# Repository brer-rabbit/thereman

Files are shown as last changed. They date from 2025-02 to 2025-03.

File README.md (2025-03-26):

# Annoying Thereman - light sensitive buzzing companion

This repo contains the design and build info for Thereman, a light sensitive buzzing companion.  Very useful for a variety of buzzing sounds.

The Thereman contains two LDRs (Light Dependent Resistors) and a dual 555 timer pretty much like an Atari Punk Console.  The LDRs control pitch and pulse width.

# Build

The kit contains a PCB with the dual 555 timer (a 556), the LDRs, eye LEDs, and some passive components on the front, pre-soldered (lead free).  The back requires soldering a couple components.  I'm assuming you're using regular solder wire (if you're using liquid solder I assume you know what you're doing).

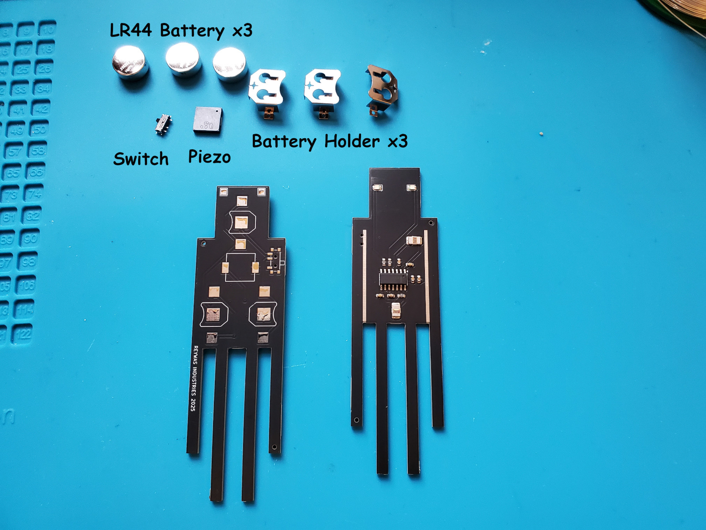
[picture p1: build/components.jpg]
Components shown with front and back of Thereman


## Prep

Tin the pads first.  Shown below, tin the pads marked in green.  The pads in red should not be tinned.

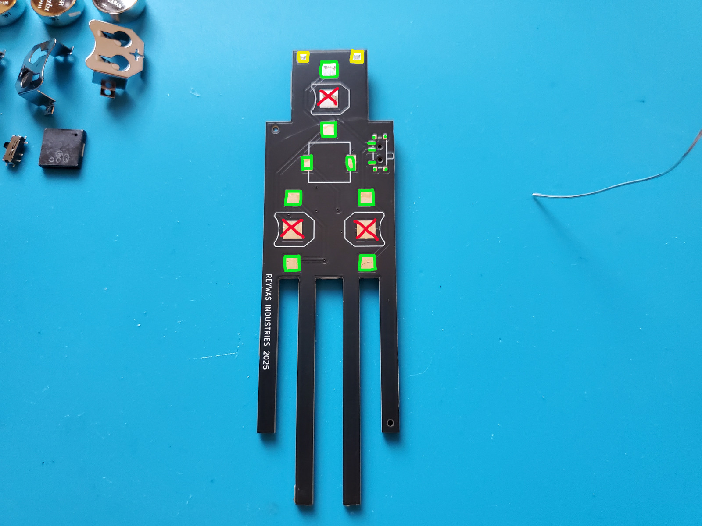
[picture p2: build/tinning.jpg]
Tin pads shown in green


Optionally: if you'd like a loop of wire to hang the Thereman from, tin the yellow pads.  These are not electrically connected.  You can solder a wire to one or between them to create a loop.

Just a touch of solder for tinning please.  And you don't want solder poking up.  Keep it flat and level so components lay flat.

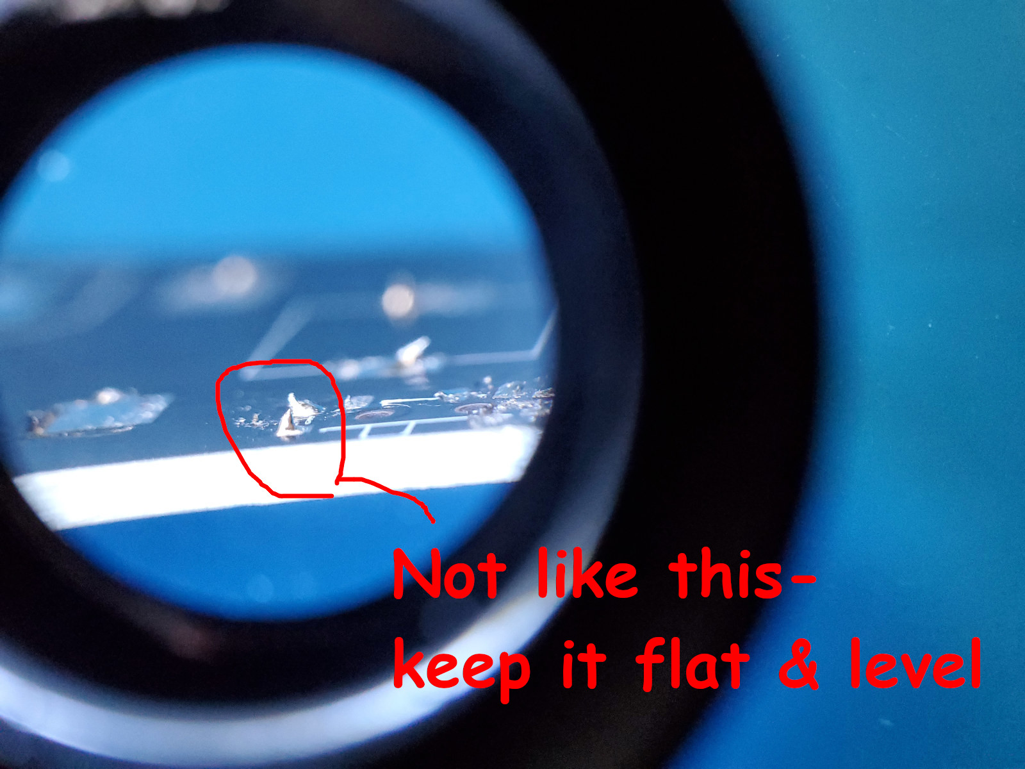
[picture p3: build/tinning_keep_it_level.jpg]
This is not even, keep it flat


## Switch

The switch has a few small pads; it's easiest to do this first before the other components clutter the space.  The on/off switch sticks out the side of the Thereman.

Once done congrats!  You've soldered the smallest component of the project.  Everything else ought to be easy.

## Piezo Buzzer

The piezo buzzer is the black square that is responsible for the great sound of the Thereman.  It goes in the very middle; it's not polarized and can be installed in either direction.

## Battery Retainers

Install the top battery retainer.  Two of the three pads keep the battery retainer in place and make an electrical connection.  The middle pad is not soldered.  Of the two pads to solder, the pad that is at the top may be easiest to do first.  Then the pad right next to the piezo.

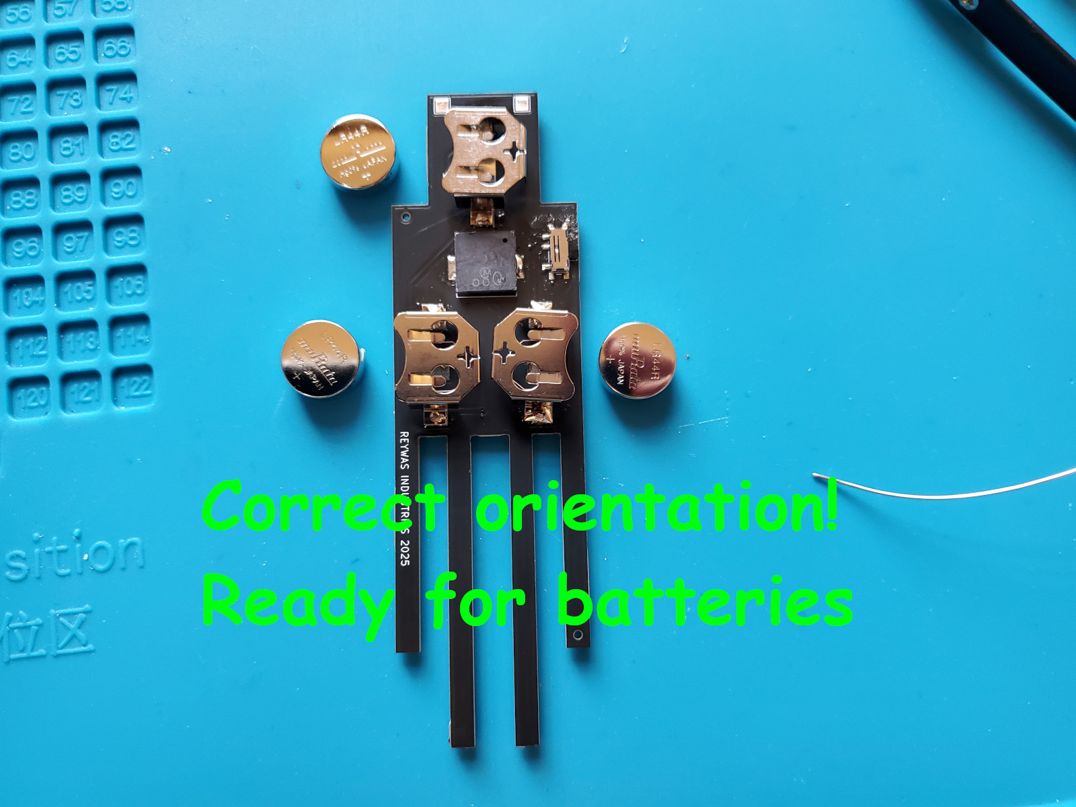
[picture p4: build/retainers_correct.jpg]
Correct orientation of battery retainers


The bottom two battery retainers need to be oriented so one can insert batteries.

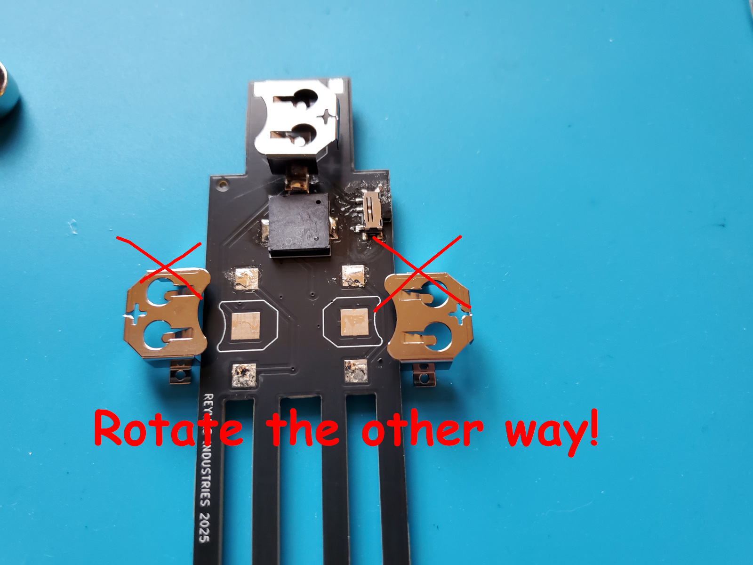
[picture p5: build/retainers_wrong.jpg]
Nope, flip those battery retainers around


Also, keep the battery retainers slightly apart so they do not touch.

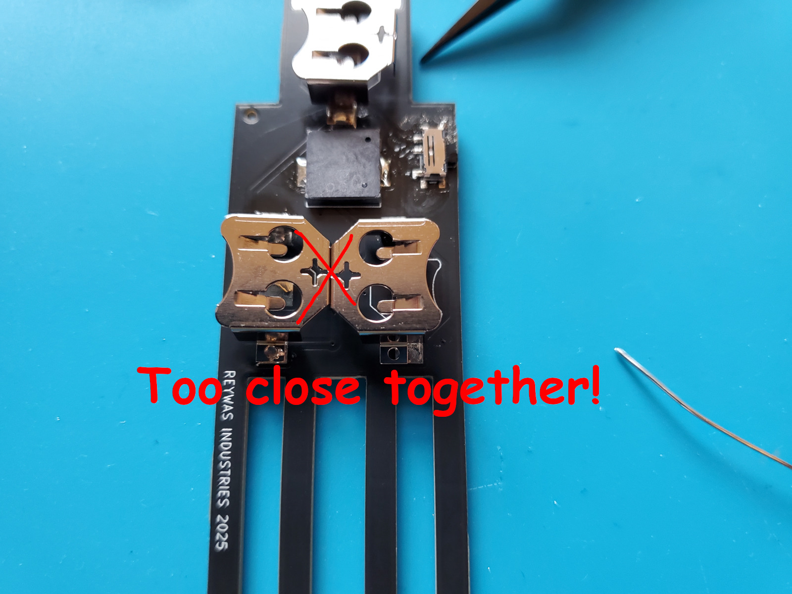
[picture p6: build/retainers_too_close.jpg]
Keep the retainers a bit apart, this is too close


## Cleaning

A bit of isopropyl alcohol can be used for cleaning.  Try not to get alcohol in the switch or the piezo buzzer.

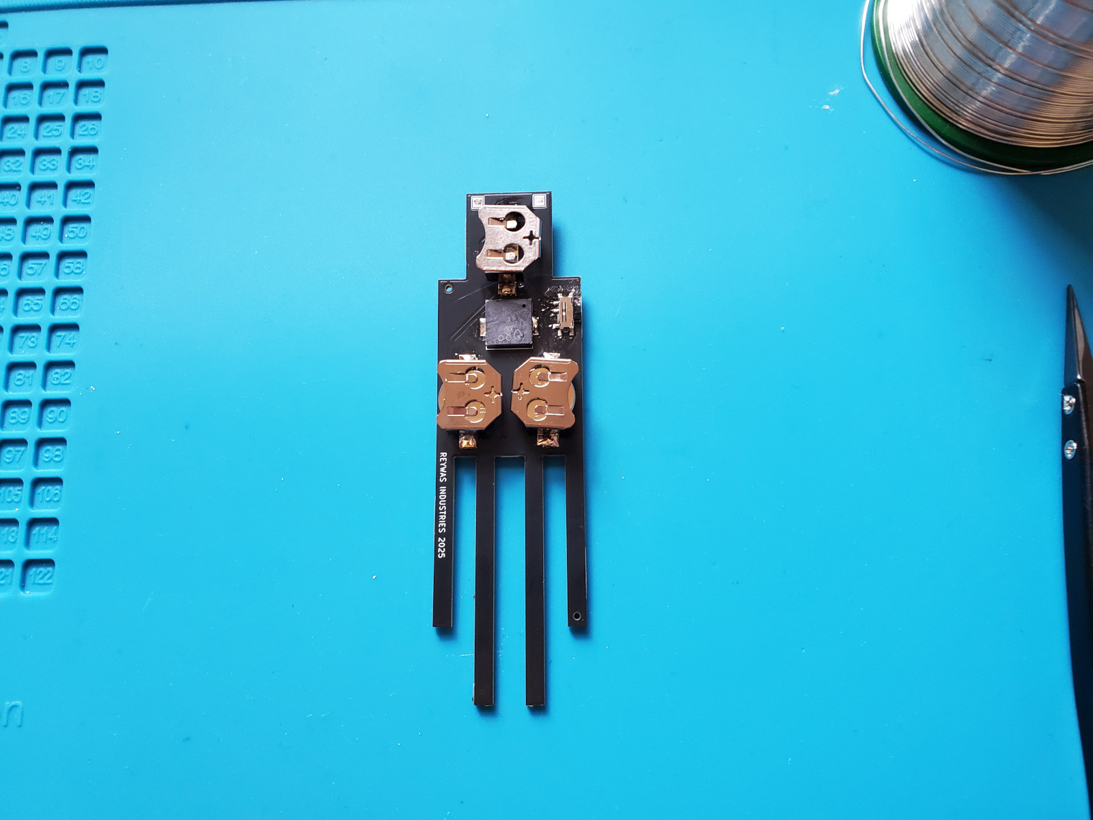
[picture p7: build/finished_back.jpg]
Finished backside ready for cleaning


## Flip the switch!

With batteries installed (positive side facing up in retainer) flip the switch.  Your Thereman should now start annoying!

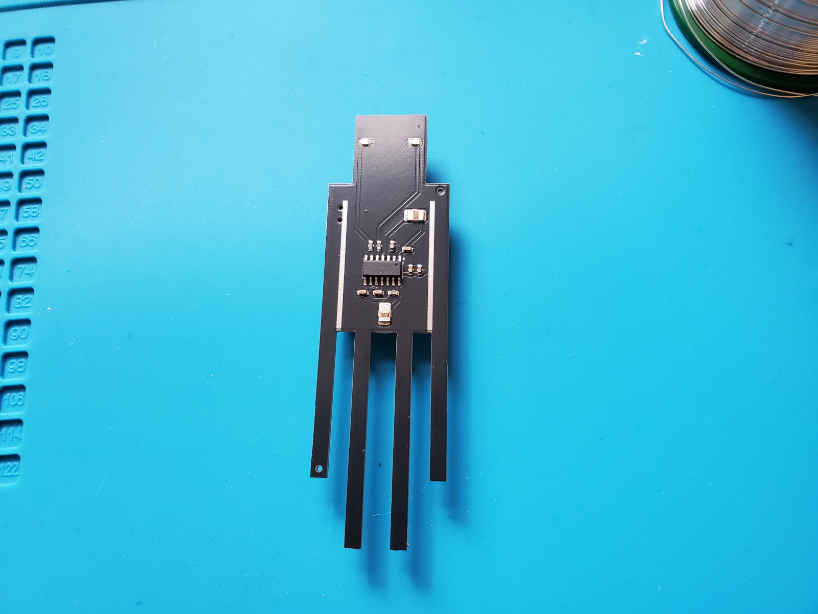
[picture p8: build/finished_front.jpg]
Front


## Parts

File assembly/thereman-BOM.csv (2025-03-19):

Comment | Designator | Footprint | LCSC Part #
2u2 | C1 | Capacitor_SMD:C_0603_1608Metric | C23630
47n | C2,C5 | Capacitor_SMD:C_0603_1608Metric | C1622
100n | C3,C4,C6 | Capacitor_SMD:C_0603_1608Metric | C14663
LED | D1,D2 | LED_SMD:LED_0805_2012Metric | C7371915
10k | R1 | Resistor_SMD:R_0603_1608Metric | C25804
R_Photo | R2,R3 | Library:SMD2.4x3.6 | C2904880
220 | R5,R6 | Resistor_SMD:R_0603_1608Metric | C22962
LM556 | U1 | Package_SO:SOIC-14_3.9x8.7mm_P1.27mm | C18164404

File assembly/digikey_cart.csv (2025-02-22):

Index | Quantity | Part Number | Manufacturer Part Number | Description | Customer Reference | Available | Backorder | Unit Price | Extended Price USD
1 | 10 | 296-26240-1-ND | NE556DR | IC OSC TIMER DUAL 100KHZ 14SOIC |  | 10 | 0 | 0.25500 | 2.55
2 | 10 | 36-3034-ND | 3034 | BATTERY RETAINER COIN 20MM SMD |  | 10 | 0 | 0.33600 | 3.36
3 | 10 | 1497-XZFRS54FVF-1CT-ND | XZFRS54FVF-1 | 2.0X1.2MM PURPLE SMD 0805 LED |  | 10 | 0 | 0.56500 | 5.65
4 | 10 | 296-24348-1-ND | CD4030BM96 | IC GATE XOR 4CH 2-INP 14SOIC |  | 10 | 0 | 0.25500 | 2.55

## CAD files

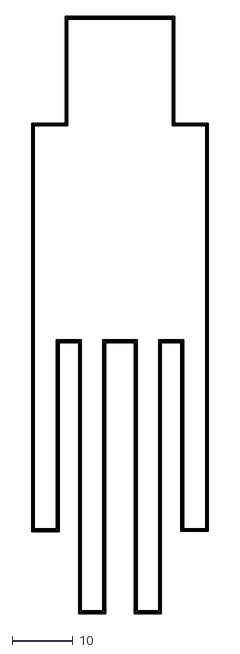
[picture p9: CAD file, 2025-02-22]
thereman.dxf
29.0 x 98.0

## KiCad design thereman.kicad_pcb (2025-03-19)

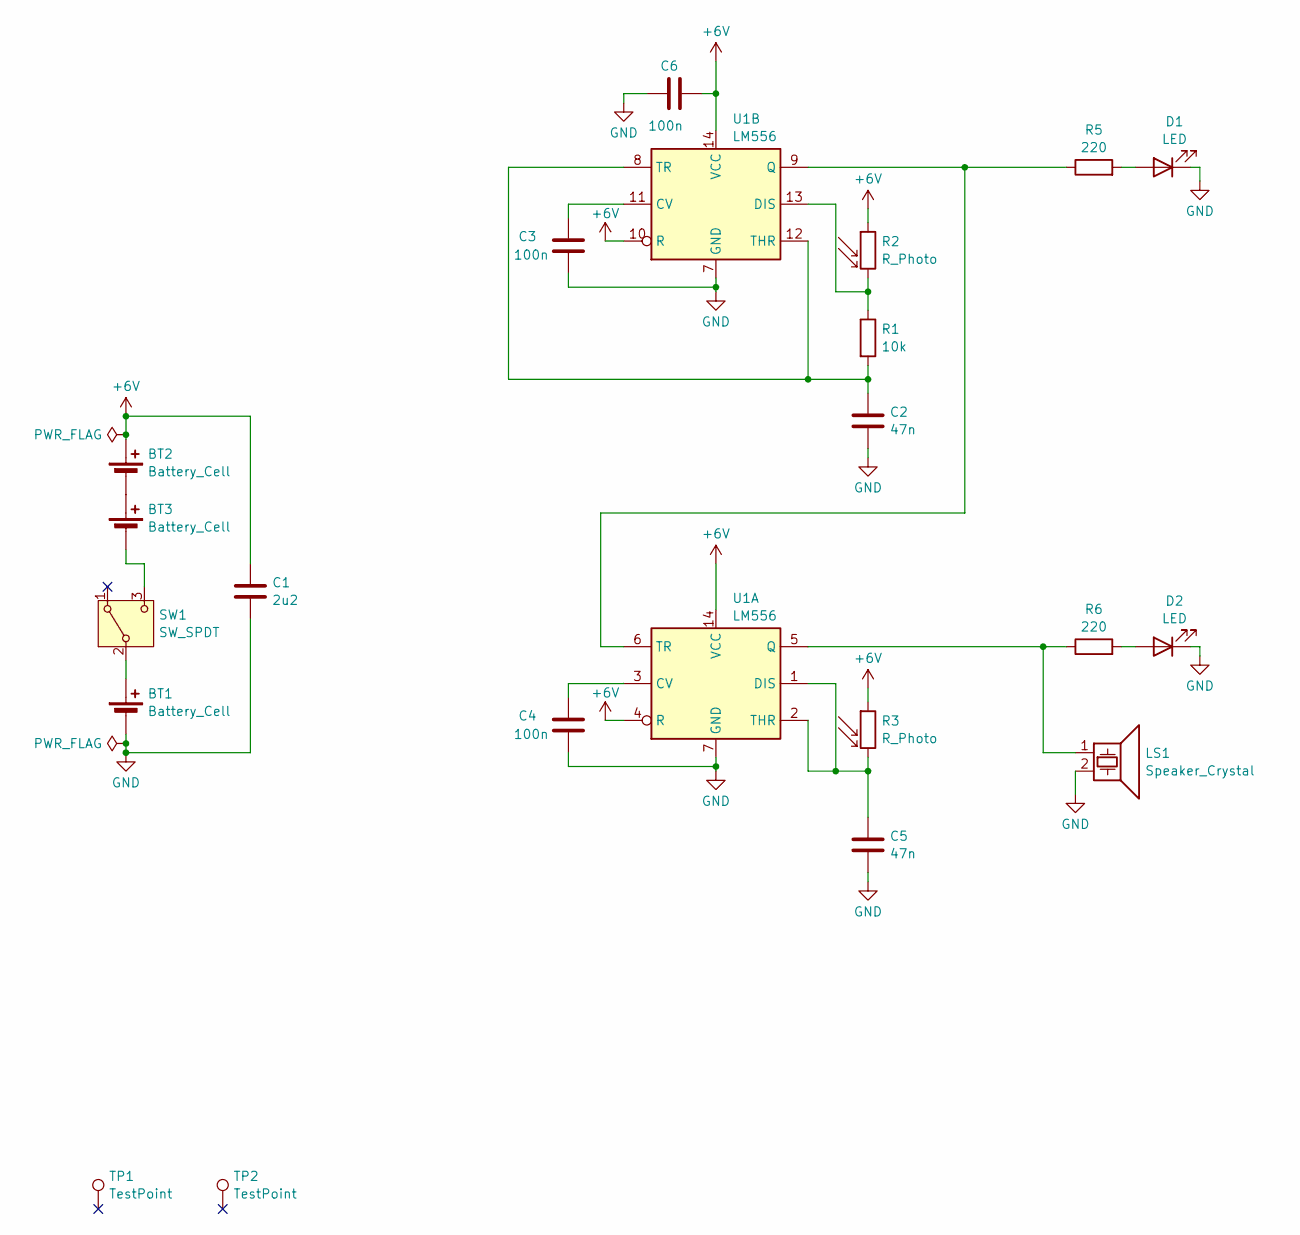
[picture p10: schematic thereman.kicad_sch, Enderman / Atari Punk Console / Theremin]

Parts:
BT1, BT2, BT3: Battery_Cell; BatteryHolder_Keystone_2996; Digikey 36-2996-ND
C1: 2u2; C_0603_1608Metric; LCSC C23630
C2, C5: 47n; C_0603_1608Metric; LCSC C1622
C3, C4, C6: 100n; C_0603_1608Metric; LCSC C14663
D1, D2: LED; LED_0805_2012Metric; Digikey 1497-XZFRS54FVF-1CT-ND
LS1: Speaker_Crystal; Piezo PKMCS0909E4000-R1; Digikey 490-9647-1-ND
R1: 10k; R_0603_1608Metric; LCSC C25804
R2, R3: R_Photo; SMD2.4x3.6; LCSC C2904880
R5, R6: 220; R_0603_1608Metric; LCSC C22962
SW1: SW_SPDT; SW_SPDT_PCM12; Digikey 732-13665-1-ND
TP1, TP2: TestPoint; TestPoint_Pad_2.0x2.0mm
U1: LM556; SOIC-14_3.9x8.7mm_P1.27mm; Digikey 296-1338-1-ND

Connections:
+6V: BT2.1 (+), C1.1, C6.2, R2.1, R3.1, U1.4 (R), U1.10 (R), U1.14 (VCC)
GND: BT1.2 (-), C1.2, C2.2, C3.2, C4.2, C5.2, C6.1, D1.1 (K), D2.1 (K), LS1.2, U1.7 (GND)
unnamed: BT1.1 (+), SW1.2 (B)
unnamed: BT2.2 (-), BT3.1 (+)
unnamed: BT3.2 (-), SW1.3 (C)
unnamed: D1.2 (A), R5.2
unnamed: D2.2 (A), R6.2
unnamed: C4.1, U1.3 (CV)
unnamed: C5.1, R3.2, U1.1 (DIS), U1.2 (THR)
unnamed: LS1.1, R6.1, U1.5 (Q)
unnamed: R5.1, U1.6 (TR), U1.9 (Q)
unnamed: C3.1, U1.11 (CV)
unnamed: R1.1, R2.2, U1.13 (DIS)
unnamed: C2.1, R1.2, U1.8 (TR), U1.12 (THR)

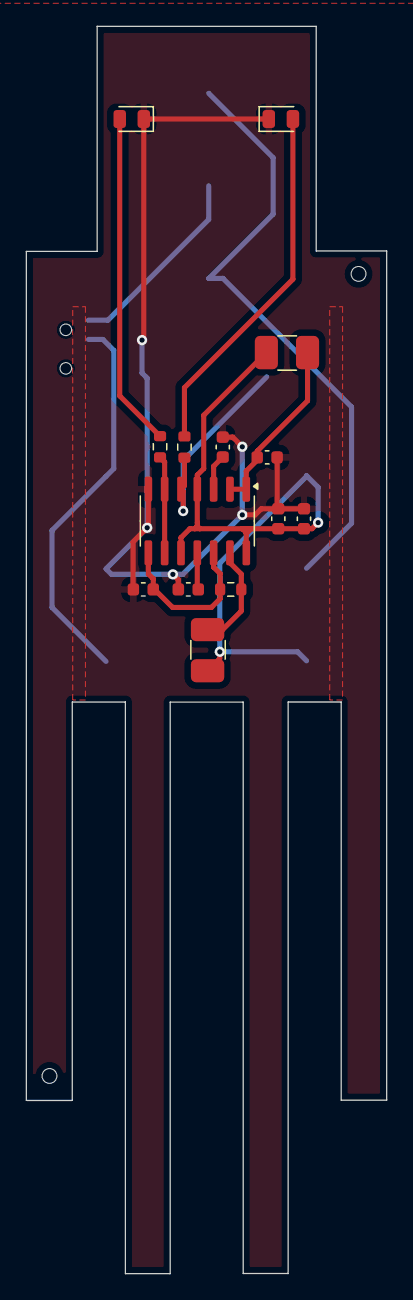
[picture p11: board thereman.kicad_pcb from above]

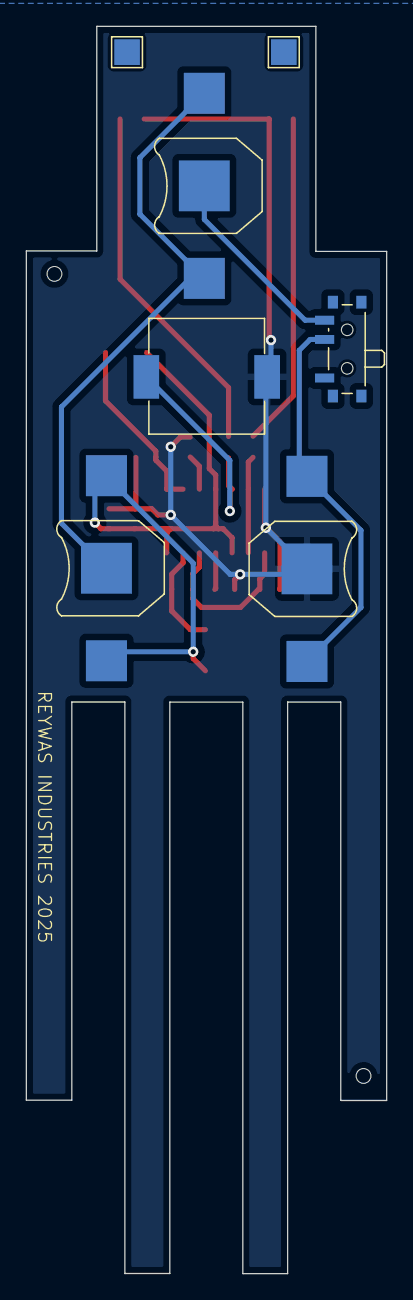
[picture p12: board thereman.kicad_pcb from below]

Board: 2 copper layers, 28.0 x 97.0 mm, 21 parts (7 on the bottom side), 14 nets.

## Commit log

2025-02-24 v2.0 RTM
    [enderman-BOM.csv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]
2025-03-05 minimize vias
    [enderman.kicad_pcb]
2025-03-05 routed atari punk console version
    [enderman.kicad_pcb, enderman.kicad_sch]
2025-03-07 updated piezo footprint. Better routing. Added on/off switch. Hid some vias under chip.
    [enderman.kicad_pcb, enderman.kicad_sch]
2025-03-19 atari punk version
    [enderman-BOM.csv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]
